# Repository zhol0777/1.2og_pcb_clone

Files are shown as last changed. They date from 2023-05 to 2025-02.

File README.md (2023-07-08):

# 1.2og repro pcb

| front | back | lightbar |
| --- | --- | --- |
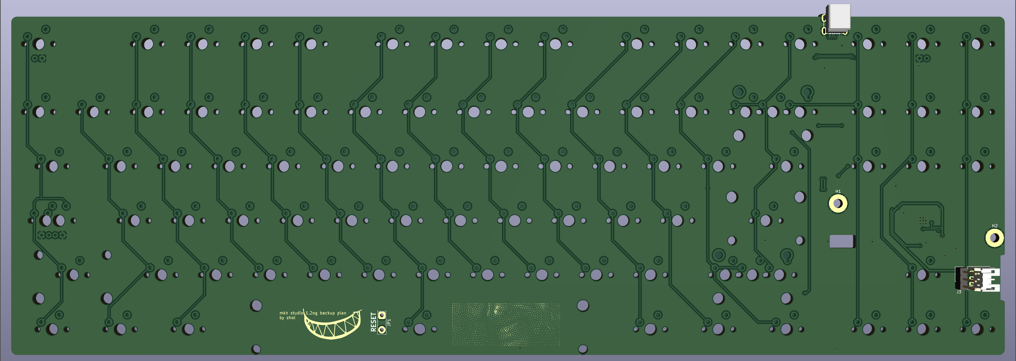
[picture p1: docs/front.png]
front of pcb
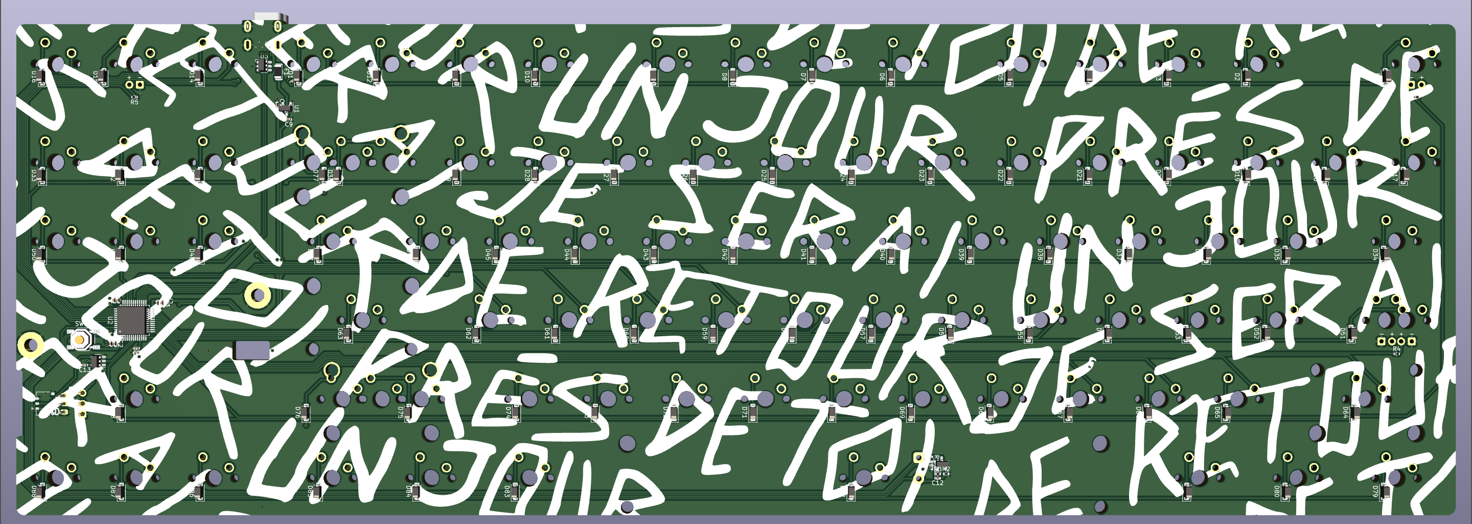
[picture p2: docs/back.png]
back of pcb
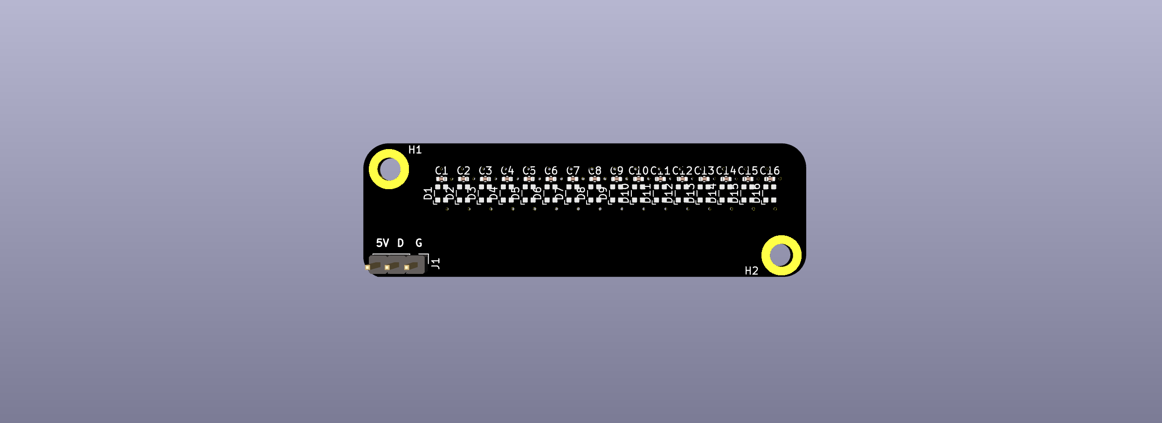
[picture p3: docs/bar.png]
lightbar
|  |  |  |

unfinished attempt to re-create pcb and lightbar for matrix 1.2og.

this has been designed by using pcb edge cuts and plate file that were provided courtesy of astro of matrixlab [here](https://geekhack.org/index.php?topic=106122.msg2901076#msg2901076). without it, re-creating the PCB would be a more maddening and expensive experience. it has 19.02mm x 19.02mm spacing (mostly). 

indicator LEDs on scroll lock and caps lock. JST headers are for s3b ph 3 pin, since that's what it looks like from watching youtube build videos.

## warnings/differences

* The official plate file is treated as the source of truth for where switches should be placed
  * The official 1.2OG PCB edge cuts provided by astro has some arcane spacing rules -
    * 19.02mm on y axis for every row
    * 19.02mm on x axis on first three rows and all arrow keys
    * 19.00mm on row 4 on the main cluster of keys (not arrow keys)
      * The right shift key might still be at where it would be at 19.02mm spacing. The left shift key, i'm not sure, I just placed it where it would have been at 19.02mm spacing.
    * 18.978mmm on modifier keys in the bottom row (not sure if spacebar key is affected)
  * all of this is ignored in favor of sticking with plate dimensions or expected plate dimensions, which are 19.02mm x 19.02mm spacing, EXCEPT
    * 19.024mm y-axis spacing between the function row and regular key cluster
    * the distance between the `M` and `Comma` key is 19.03mm.
* lightbar mounting holes on PCB are slightly off-spec, and in here are plated m3 (edge cuts seem to imply the hole is a bit wider).
* lightbar can now connected to PCB through a molex pico ezmate cable. if you don't like it, you can assemble without it, and solder the s3b connector on yourself.
  * https://www.mouser.com/ProductDetail/Molex/36920-0301 - pick these up, and cut them down the middle to solder wires direct to lightbar
* split backspace and split right shift are included, in case anyone is wants to make a plate that supports those switches. ISO left shift and enter are not included due to laziness.
* usb port placement is mostly guessing.
* 6U spacebar support is added because I miss using my hhkb pro 2.

## misc, thanks

stm32f072 schematic is courtesy of xphoenixd. thanks for teaching me how to design PCB's, man. schematic for ws2812c-2020 rgb chain is inspired by zykrah's [fuyu](https://github.com/zykrah/fuyu). voltage step-up thing for lightbar is inspired by schematic from fuyu and dededecline and olivia's [sst60](https://github.com/dededecline/SST60).

an earlier revision included a basic reset circuit provided by xyz, who also pointed out an issue in the BOM that caused one major issue with the first round of prototypes - were it not for him, I'd probably make two more rounds of protos with the same issue. all love to matthewdias, islandworks, and mel for pointing out a glaring issue with USB, and doubly so for matt for being willing to replace 0402 package resistors pro bono after xyz pointed out how a BOM mistake from me rendered the reset circuit useless. thanks to chippy, phoenix, and chill for misc. advice on how to design this.

i don't know if i'm allowed to license this, given the pcb edge cuts this is based off of were released without a license. nevertheless, they were provided by astro from matrixlab. thank you!

no working prototype has been made for this yet! beware!

## todo
1. ~~fill out BOM real good~~
2. measure and source standoffs that are good enough and ultra low profile screws
3. ~~split main pcb and lightbar pcb separately so jlcpcb production files don't keep bothering each other~~
4. adjust placement of ws2812 based on if it is too far to one side of the lightbar or the other.
5. consider alternative to ws2812 2020 if power consumption/cost reasons.
6. prototype PCB and lightbar
7. ~~firmware (come on, this is basically automated at this point)~~
8. modify lightbar to support both direct soldering and ezmate/jst ach through mouse bite/break off thing or something
  * i think there should be straight ezmate to this, it would make peoples lives so much easier (ignoring how you'd route the extra cable slack)
9. verify this works with original lightbar

## prototyping progress

first revision (in beta branch) failed due to rookie mistake of using USB symbol from one library and footprint from another - the pins between each were in reverse order of each other, which made the prototype useless. whoops! after shipping PCBs to matt for rework, some goons looked over this in kicad pcbeditor and pointed out that the pins over USB were in reverse order.

second prototype arrived 5.31.2023, and exhibited strange behavior - on boot to bootloader mode, dfu-util is able to flash the PCB seemingly fine, and then after reset, the PCB appears recognized by VIAL, at which point **every single device connected over the same USB hub** goes unresponsive. the pcb is also unresponsive. five seconds pass, the PCB dissapears from VIAL, and USB devices begin working again. something deeply bad has happened, so I've tried rearranging all the parts, validating BOM, and praying next revision works.

the latest push to main branch uses molex 0548190519, which I haven't prototyped, but shouldn't be too different otherwise.

i've bought these SMT M2 threaded spacer/standoffs so that lightbar can mount to pcb - https://www.mouser.com/ProductDetail/Wurth-Elektronik/9774015243R - you're probably supposed to use solder paste to assemble these things, but I don't have that, so I don't know, maybe I'll use solder shavings to get these things soldered on. they're slightly smaller than the m3 plated hole on pcb/lightbar, but I don't think it'll matter too much, since they should align one way or another.

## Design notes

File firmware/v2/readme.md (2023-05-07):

# zhol/backup_plan/v1

zhol/backup_plan/v1

A drop-in replacement for the Matrix 1.2OG.

* Keyboard Maintainer: [zhol](https://github.com/zhol0777)
* Hardware Supported: APM32F072
* Hardware Availability: [Github](https://github.com/zhol0777/1.2og_pcb_clone)

Make example for this keyboard (after setting up your build environment):

    make zhol/backup_plan:default

Flashing example for this keyboard:

    make zhol/backup_plan:default:flash

See the [build environment setup](https://docs.qmk.fm/#/getting_started_build_tools) and the [make instructions](https://docs.qmk.fm/#/getting_started_make_guide) for more information. Brand new to QMK? Start with our [Complete Newbs Guide](https://docs.qmk.fm/#/newbs).

## Bootloader

Enter the bootloader in 3 ways:

* **Bootmagic reset**: Hold down the key at (0,0) in the matrix (usually the top left key or Escape) and plug in the keyboard
* **Physical reset button**: Press and hold the reset button on the rear of the pcb (or short the reset jumper beside the spacebar key) for at least 3 seconds.
* **Keycode in layout**: Press the key mapped to `QK_BOOT` if it is available

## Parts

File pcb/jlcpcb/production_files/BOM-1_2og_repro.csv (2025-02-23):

Comment | Designator | Footprint | LCSC | Quantity
10nF | C5 | C_0402_1005Metric | C15195 | 1
100nF | C1,C2,C3,C4 | C_0402_1005Metric | C1525 | 4
S3B | J4 | JST_PH_S3B-PH-K_1x03_P2.00mm_Horizontal | C157929 | 1
4.7uF | C12,C6,C7 | C_0402_1005Metric | C23733 | 3
548190519 | J2 | Molex-0548190519 | C240850 | 1
220 | R2,R3 | R_0402_1005Metric | C25091 | 2
100k | R6 | R_0402_1005Metric | C25741 | 1
10k | R1,R5 | R_0402_1005Metric | C25744 | 2
PRTR5V0U2X | D94 | SOT-143 | C2827688 | 1
Pico EzMate | J1 | Molex_Pico-EZmate_78171-0003_1x03-1MP_P1.20mm_Vertical | C2997426 | 1
SW_Push | SW95 | SW_SPST_TL3342 | C318884 | 1
1uF | C10,C11,C8,C9 | C_0402_1005Metric | C52923 | 4
XC6206PxxxMR | U1 | SOT-23 | C5446 | 1
SN74LVC1T45DBV | U3 | SOT-23-6-routable | C7843 | 1
D_Small | D1,D10,D11,D12,D13,D14,D15,D16,D17,D18,D19,D2,D20,D21,D22,D23,D24,D25,D26,D27,D28,D29,D3,D30,D31,D32,D33,D34,D35,D36,D37,D38,D39,D4,D40,D41,D42,D43,D44,D45,D46,D47,D48,D49,D5,D50,D51,D52,D53,D54,D55,D56,D57,D58,D59,D6,D60,D61,D62,D63,D64,D65,D66,D67,D68,D69,D7,D70,D71,D72,D73,D74,D75,D76,D77,D78,D79,D8,D80,D81,D82,D83,D84,D85,D86,D87,D88,D9,D93 | D_SOD-123 | C81598 | 89
STM32F072C8Tx | U2 | LQFP-48_7x7mm_P0.5mm | C81720 | 1
2N7002 | Q1 | SOT-23 | C8545 | 1
500mA | F1 | Fuse_1206_3216Metric | C883122 | 1

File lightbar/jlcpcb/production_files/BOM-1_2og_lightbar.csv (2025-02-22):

Comment | Designator | Footprint | LCSC | Quantity
100nF | C1,C10,C11,C12,C13,C14,C15,C16,C2,C3,C4,C5,C6,C7,C8,C9 | C_0402_1005Metric | C1525 | 16
500 | R1,R2 | R_0805_2012Metric | C2828711 | 2
SK6812_EC15 | D1,D10,D11,D12,D13,D14,D15,D16,D2,D3,D4,D5,D6,D7,D8,D9 | LED_SK6812_EC15_1.5x1.5mm | C2890035 | 16
Conn_01x03_Shielded | J2 | Molex_Pico-EZmate_78171-0003_1x03-1MP_P1.20mm_Vertical | C2997426 | 1

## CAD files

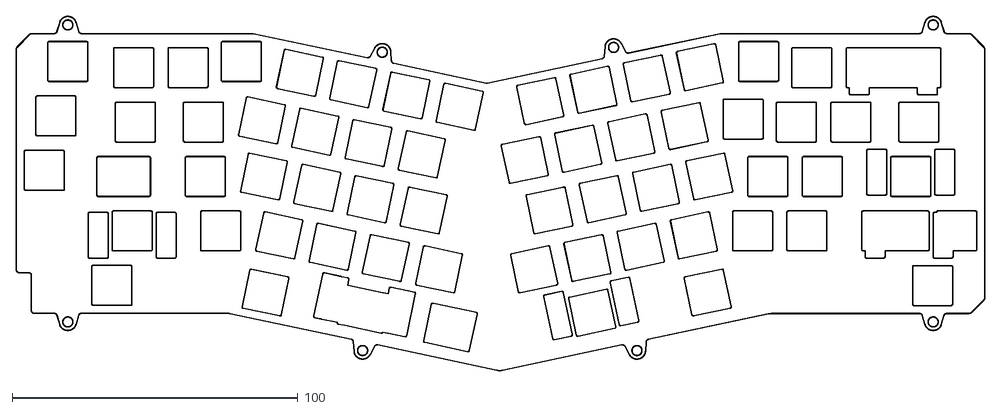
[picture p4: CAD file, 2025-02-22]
pcb/1_2og_repro-Edge_Cuts.dxf
338.8 x 123.9

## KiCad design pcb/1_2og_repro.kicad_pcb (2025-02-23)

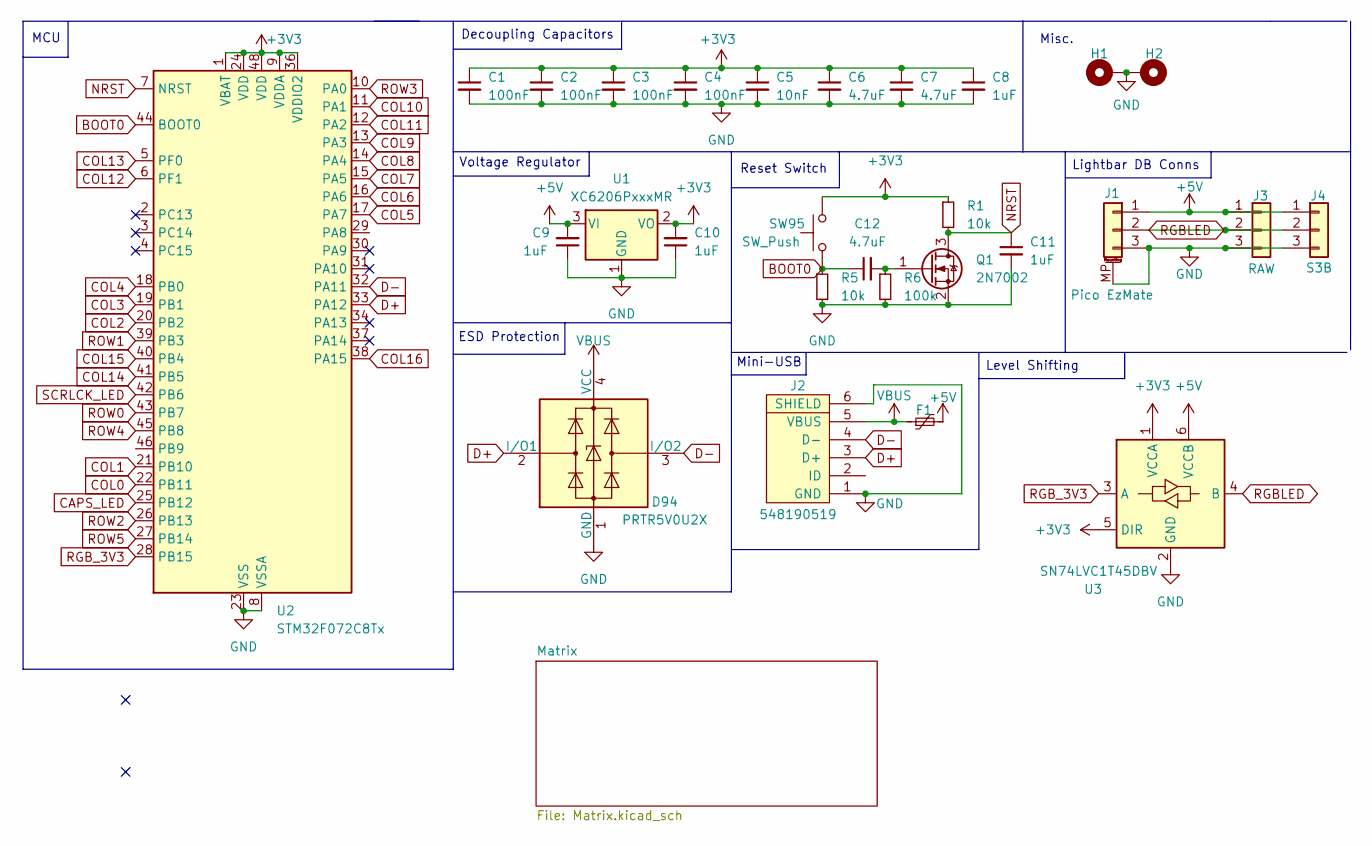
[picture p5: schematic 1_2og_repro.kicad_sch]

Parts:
C1, C2, C3, C4: 100nF; C_0402_1005Metric
C5: 10nF; C_0402_1005Metric
C6, C7, C12: 4.7uF; C_0402_1005Metric
C8, C9, C10, C11: 1uF; C_0402_1005Metric
D94: PRTR5V0U2X; SOT-143
F1: 500mA; Fuse_1206_3216Metric
H1, H2: MountingHole_Pad; MountingHole_3mm_Pad
J1: Pico EzMate; Molex_Pico-EZmate_78171-0003_1x03-1MP_P1.20mm_Vertical
J2: 548190519; Molex-0548190519
J3: RAW; PinHeader_1x03_P2.54mm_Vertical
J4: S3B; JST_PH_S3B-PH-K_1x03_P2.00mm_Horizontal
Q1: 2N7002; SOT-23
R1, R5: 10k; R_0402_1005Metric
R6: 100k; R_0402_1005Metric
SW95: SW_Push; SW_SPST_TL3342
U1: XC6206PxxxMR; SOT-23
U2: STM32F072C8Tx; LQFP-48_7x7mm_P0.5mm
U3: SN74LVC1T45DBV; SOT-23-6

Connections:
+3V3: C1.1, C2.1, C3.1, C4.1, C5.1, C6.1, C7.1, C8.1, C10.2, R1.1, SW95.2, U1.2 (VO), U2.1 (VBAT), U2.9 (VDDA), U2.24 (VDD), U2.36 (VDDIO2), U2.48 (VDD), U3.1 (VCCA), U3.5 (DIR)
+5V: C9.2, F1.2, J1.1, J3.1, J4.1, U1.3 (VI), U3.6 (VCCB)
BOOT0: C12.1, R5.1, SW95.1, U2.44 (BOOT0)
CAPS_LED: U2.25 (PB12); also elsewhere on the board
COL0: U2.22 (PB11); also elsewhere on the board
COL1: U2.21 (PB10); also elsewhere on the board
COL2: U2.20 (PB2); also elsewhere on the board
COL3: U2.19 (PB1); also elsewhere on the board
COL4: U2.18 (PB0); also elsewhere on the board
COL5: U2.17 (PA7); also elsewhere on the board
COL6: U2.16 (PA6); also elsewhere on the board
COL7: U2.15 (PA5); also elsewhere on the board
COL8: U2.14 (PA4); also elsewhere on the board
COL9: U2.13 (PA3); also elsewhere on the board
COL10: U2.11 (PA1); also elsewhere on the board
COL11: U2.12 (PA2); also elsewhere on the board
COL12: U2.6 (PF1); also elsewhere on the board
COL13: U2.5 (PF0); also elsewhere on the board
COL14: U2.41 (PB5); also elsewhere on the board
COL15: U2.40 (PB4); also elsewhere on the board
COL16: U2.38 (PA15); also elsewhere on the board
D+: D94.2 (I/O1), J2.3 (D+), U2.33 (PA12)
D-: D94.3 (I/O2), J2.4 (D-), U2.32 (PA11)
GND: C1.2, C2.2, C3.2, C4.2, C5.2, C6.2, C7.2, C8.2, C9.1, C10.1, C11.2, D94.1 (GND), H1.1, H2.1, J1.3, J1.MP (MountPin), J2.1 (GND), J2.6 (SHIELD), J3.3, J4.3, Q1.2 (S), R5.2, R6.2, U1.1 (GND), U2.8 (VSSA), U2.23 (VSS), U2.35 (VSS), U2.47 (VSS), U3.2 (GND); also elsewhere on the board
NRST: C11.1, Q1.3 (D), R1.2, U2.7 (NRST)
unnamed: C12.2, Q1.1 (G), R6.1
RGBLED: J1.2, J3.2, J4.2, U3.4 (B)
RGB_3V3: U2.28 (PB15), U3.3 (A)
ROW0: U2.43 (PB7); also elsewhere on the board
ROW1: U2.39 (PB3); also elsewhere on the board
ROW2: U2.26 (PB13); also elsewhere on the board
ROW3: U2.10 (PA0); also elsewhere on the board
ROW4: U2.45 (PB8); also elsewhere on the board
ROW5: U2.27 (PB14); also elsewhere on the board
SCRLCK_LED: U2.42 (PB6); also elsewhere on the board
VBUS: D94.4 (VCC), F1.1, J2.5 (VBUS)

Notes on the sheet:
Level Shifting
Mini-USB
Reset Switch
MCU
ESD Protection
Voltage Regulator
Misc.
Lightbar DB Conns
Decoupling Capacitors

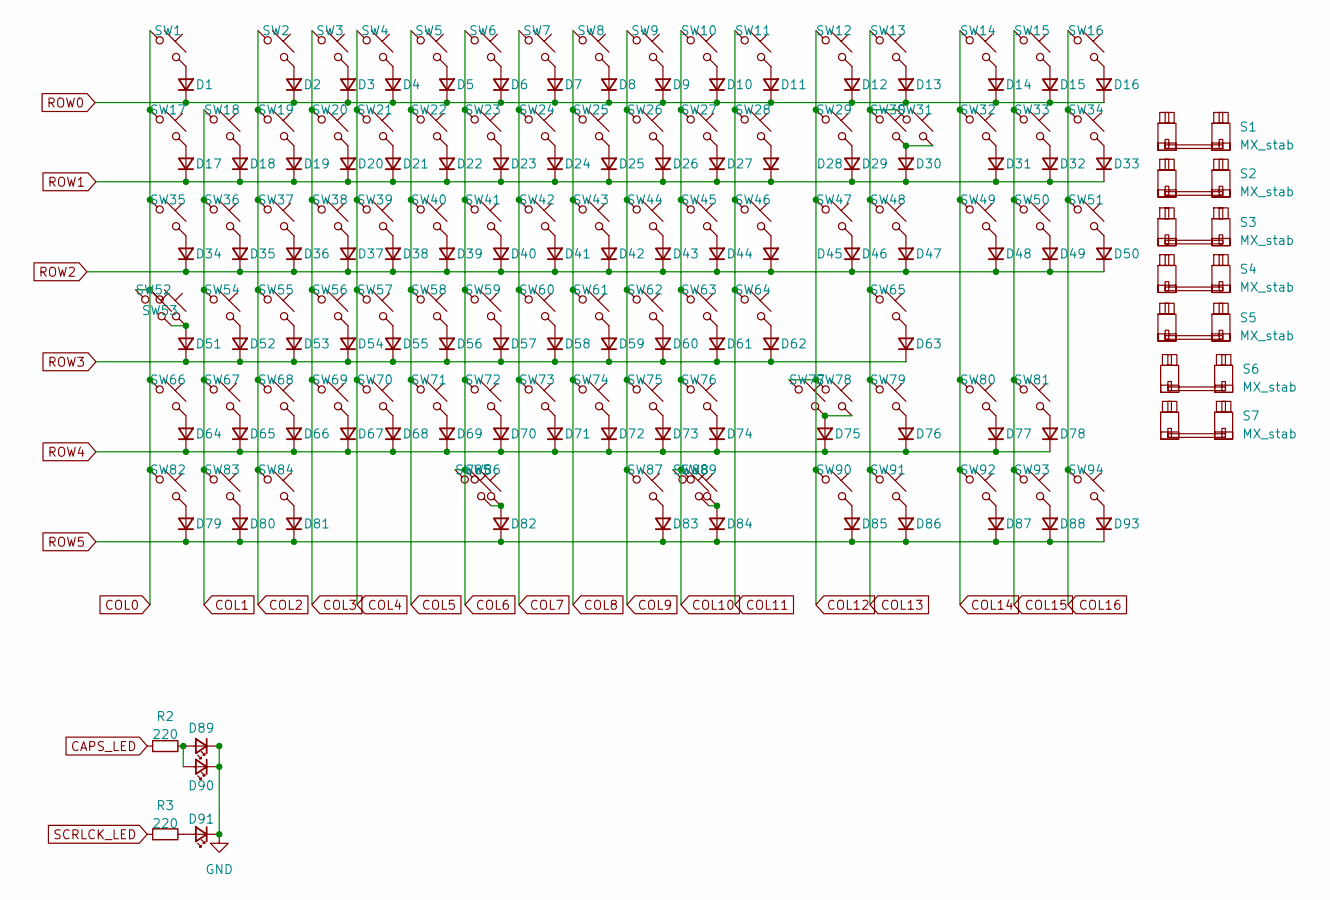
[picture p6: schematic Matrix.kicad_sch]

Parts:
D1, D2, D3, D4, D5, D6, D7, D8, D9, D10, D11, D12, D13, D14, D15, D16, D17, D18, D19, D20, D21, D22, D23, D24, D25, D26, D27, D28, D29, D30, D31, D32, D33, D34, D35, D36, D37, D38, D39, D40, D41, D42, D43, D44, D45, D46, D47, D48, D49, D50, D51, D52, D53, D54, D55, D56, D57, D58, D59, D60, D61, D62, D63, D64, D65, D66, D67, D68, D69, D70, D71, D72, D73, D74, D75, D76, D77, D78, D79, D80, D81, D82, D83, D84, D85, D86, D87, D88, D93: D_Small; D_SOD-123
D89, D91: LED_Small; LED_MX_3mm
D90: LED_Small; LED_MX_3mm-ROT
R2, R3: 220; R_0402_1005Metric
S1: MX_stab; STAB_MX_P_2u
S2, S3: MX_stab; STAB_MX_2.25u
S4: MX_stab; STAB_MX_P_2.75u
S5: MX_stab; STAB_MX_7u
S6: MX_stab; STAB_MX_6u
S7: MX_stab; STAB_MX_10u
SW1, SW2, SW3, SW4, SW5, SW6, SW7, SW8, SW9, SW10, SW11, SW12, SW13, SW14, SW15, SW16, SW17, SW18, SW19, SW20, SW21, SW22, SW23, SW24, SW25, SW26, SW27, SW28, SW29, SW30, SW31, SW32, SW33, SW34, SW36, SW37, SW38, SW39, SW40, SW41, SW42, SW43, SW44, SW45, SW46, SW47, SW49, SW50, SW51, SW54, SW55, SW56, SW57, SW58, SW59, SW60, SW61, SW62, SW63, SW64, SW65, SW66, SW67, SW68, SW69, SW70, SW71, SW72, SW73, SW74, SW75, SW76, SW78, SW79, SW80, SW81, SW83, SW85, SW86, SW88, SW90, SW92, SW93, SW94: MX_SW_solder; SW_MX_1u
SW35, SW48, SW82, SW84, SW87, SW89, SW91: MX_SW_solder; SW_MX_1.5u
SW52: MX_SW_solder; SW_MX_1.75u_STP_1.25
SW53, SW77: MX_SW_solder; SW_MX_1.75u

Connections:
CAPS_LED: R2.1; also elsewhere on the board
COL0: SW1.1, SW17.1, SW35.1, SW52.1, SW53.1, SW66.1, SW82.1; also elsewhere on the board
COL1: SW18.1, SW36.1, SW54.1, SW67.1, SW83.1; also elsewhere on the board
COL2: SW2.1, SW19.1, SW37.1, SW55.1, SW68.1, SW84.1; also elsewhere on the board
COL3: SW3.1, SW20.1, SW38.1, SW56.1, SW69.1; also elsewhere on the board
COL4: SW4.1, SW21.1, SW39.1, SW57.1, SW70.1; also elsewhere on the board
COL5: SW5.1, SW22.1, SW40.1, SW58.1, SW71.1; also elsewhere on the board
COL6: SW6.1, SW23.1, SW41.1, SW59.1, SW72.1, SW85.1, SW86.1; also elsewhere on the board
COL7: SW7.1, SW24.1, SW42.1, SW60.1, SW73.1; also elsewhere on the board
COL8: SW8.1, SW25.1, SW43.1, SW61.1, SW74.1; also elsewhere on the board
COL9: SW9.1, SW26.1, SW44.1, SW62.1, SW75.1, SW87.1; also elsewhere on the board
COL10: SW10.1, SW27.1, SW45.1, SW63.1, SW76.1, SW88.1, SW89.1; also elsewhere on the board
COL11: SW11.1, SW28.1, SW46.1, SW64.1; also elsewhere on the board
COL12: SW12.1, SW29.1, SW47.1, SW77.1, SW78.1, SW90.1; also elsewhere on the board
COL13: SW13.1, SW30.1, SW31.1, SW48.1, SW65.1, SW79.1, SW91.1; also elsewhere on the board
COL14: SW14.1, SW32.1, SW49.1, SW80.1, SW92.1; also elsewhere on the board
COL15: SW15.1, SW33.1, SW50.1, SW81.1, SW93.1; also elsewhere on the board
COL16: SW16.1, SW34.1, SW51.1, SW94.1; also elsewhere on the board
GND: D89.1 (K), D90.1 (K), D91.1 (K); also elsewhere on the board
unnamed: D1.2 (A), SW1.2
unnamed: D2.2 (A), SW2.2
unnamed: D3.2 (A), SW3.2
unnamed: D4.2 (A), SW4.2
unnamed: D5.2 (A), SW5.2
unnamed: D6.2 (A), SW6.2
unnamed: D7.2 (A), SW7.2
unnamed: D8.2 (A), SW8.2
unnamed: D9.2 (A), SW9.2
unnamed: D10.2 (A), SW10.2
unnamed: D11.2 (A), SW11.2
unnamed: D12.2 (A), SW12.2
unnamed: D13.2 (A), SW13.2
unnamed: D14.2 (A), SW14.2
unnamed: D15.2 (A), SW15.2
unnamed: D16.2 (A), SW16.2
unnamed: D17.2 (A), SW17.2
unnamed: D18.2 (A), SW18.2
unnamed: D19.2 (A), SW19.2
unnamed: D20.2 (A), SW20.2
unnamed: D21.2 (A), SW21.2
unnamed: D22.2 (A), SW22.2
unnamed: D23.2 (A), SW23.2
unnamed: D24.2 (A), SW24.2
unnamed: D25.2 (A), SW25.2
unnamed: D26.2 (A), SW26.2
unnamed: D27.2 (A), SW27.2
unnamed: D28.2 (A), SW28.2
unnamed: D29.2 (A), SW29.2
unnamed: D30.2 (A), SW30.2, SW31.2
unnamed: D31.2 (A), SW32.2
unnamed: D32.2 (A), SW33.2
unnamed: D33.2 (A), SW34.2
unnamed: D34.2 (A), SW35.2
unnamed: D35.2 (A), SW36.2
unnamed: D36.2 (A), SW37.2
unnamed: D37.2 (A), SW38.2
unnamed: D38.2 (A), SW39.2
unnamed: D39.2 (A), SW40.2
unnamed: D40.2 (A), SW41.2
unnamed: D41.2 (A), SW42.2
unnamed: D42.2 (A), SW43.2
unnamed: D43.2 (A), SW44.2
unnamed: D44.2 (A), SW45.2
unnamed: D45.2 (A), SW46.2
unnamed: D46.2 (A), SW47.2
unnamed: D47.2 (A), SW48.2
unnamed: D48.2 (A), SW49.2
unnamed: D49.2 (A), SW50.2
unnamed: D50.2 (A), SW51.2
unnamed: D51.2 (A), SW52.2, SW53.2
unnamed: D52.2 (A), SW54.2
unnamed: D53.2 (A), SW55.2
unnamed: D54.2 (A), SW56.2
unnamed: D55.2 (A), SW57.2
unnamed: D56.2 (A), SW58.2
unnamed: D57.2 (A), SW59.2
unnamed: D58.2 (A), SW60.2
unnamed: D59.2 (A), SW61.2
unnamed: D60.2 (A), SW62.2
unnamed: D61.2 (A), SW63.2
unnamed: D62.2 (A), SW64.2
unnamed: D63.2 (A), SW65.2
unnamed: D64.2 (A), SW66.2
unnamed: D65.2 (A), SW67.2
unnamed: D66.2 (A), SW68.2
unnamed: D67.2 (A), SW69.2
unnamed: D68.2 (A), SW70.2
unnamed: D69.2 (A), SW71.2
unnamed: D70.2 (A), SW72.2
unnamed: D71.2 (A), SW73.2
unnamed: D72.2 (A), SW74.2
unnamed: D73.2 (A), SW75.2
unnamed: D74.2 (A), SW76.2
unnamed: D75.2 (A), SW77.2, SW78.2
unnamed: D76.2 (A), SW79.2
unnamed: D77.2 (A), SW80.2
unnamed: D78.2 (A), SW81.2
unnamed: D79.2 (A), SW82.2
unnamed: D80.2 (A), SW83.2
unnamed: D81.2 (A), SW84.2
unnamed: D82.2 (A), SW85.2, SW86.2
unnamed: D83.2 (A), SW87.2
unnamed: D84.2 (A), SW88.2, SW89.2
unnamed: D85.2 (A), SW90.2
unnamed: D86.2 (A), SW91.2
unnamed: D87.2 (A), SW92.2
unnamed: D88.2 (A), SW93.2
unnamed: D89.2 (A), D90.2 (A), R2.2
unnamed: D91.2 (A), R3.2
unnamed: D93.2 (A), SW94.2
ROW0: D1.1 (K), D2.1 (K), D3.1 (K), D4.1 (K), D5.1 (K), D6.1 (K), D7.1 (K), D8.1 (K), D9.1 (K), D10.1 (K), D11.1 (K), D12.1 (K), D13.1 (K), D14.1 (K), D15.1 (K), D16.1 (K); also elsewhere on the board
ROW1: D17.1 (K), D18.1 (K), D19.1 (K), D20.1 (K), D21.1 (K), D22.1 (K), D23.1 (K), D24.1 (K), D25.1 (K), D26.1 (K), D27.1 (K), D28.1 (K), D29.1 (K), D30.1 (K), D31.1 (K), D32.1 (K), D33.1 (K); also elsewhere on the board
ROW2: D34.1 (K), D35.1 (K), D36.1 (K), D37.1 (K), D38.1 (K), D39.1 (K), D40.1 (K), D41.1 (K), D42.1 (K), D43.1 (K), D44.1 (K), D45.1 (K), D46.1 (K), D47.1 (K), D48.1 (K), D49.1 (K), D50.1 (K); also elsewhere on the board
ROW3: D51.1 (K), D52.1 (K), D53.1 (K), D54.1 (K), D55.1 (K), D56.1 (K), D57.1 (K), D58.1 (K), D59.1 (K), D60.1 (K), D61.1 (K), D62.1 (K), D63.1 (K); also elsewhere on the board
ROW4: D64.1 (K), D65.1 (K), D66.1 (K), D67.1 (K), D68.1 (K), D69.1 (K), D70.1 (K), D71.1 (K), D72.1 (K), D73.1 (K), D74.1 (K), D75.1 (K), D76.1 (K), D77.1 (K), D78.1 (K); also elsewhere on the board
ROW5: D79.1 (K), D80.1 (K), D81.1 (K), D82.1 (K), D83.1 (K), D84.1 (K), D85.1 (K), D86.1 (K), D87.1 (K), D88.1 (K), D93.1 (K); also elsewhere on the board
SCRLCK_LED: R3.1; also elsewhere on the board

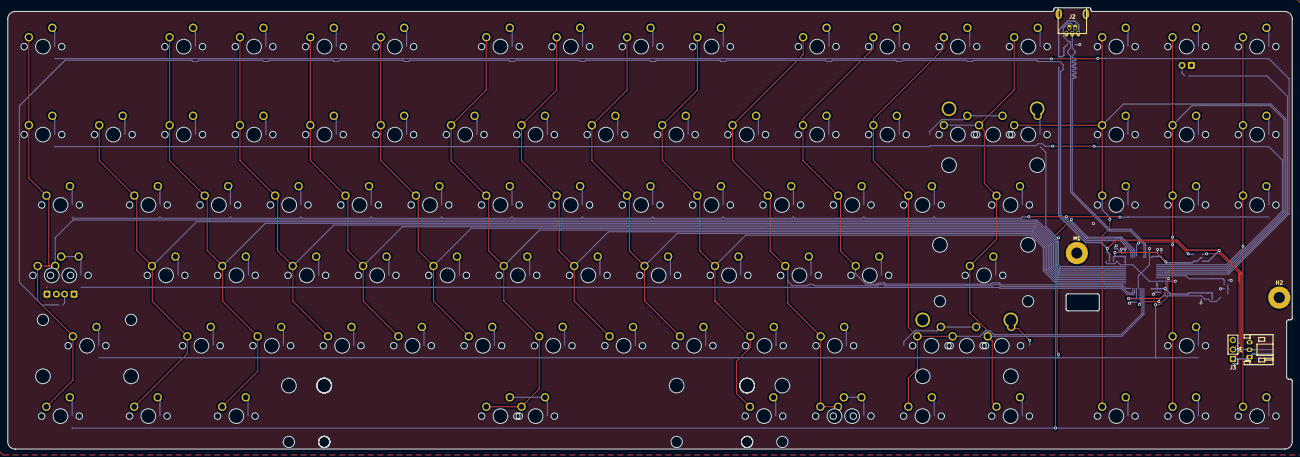
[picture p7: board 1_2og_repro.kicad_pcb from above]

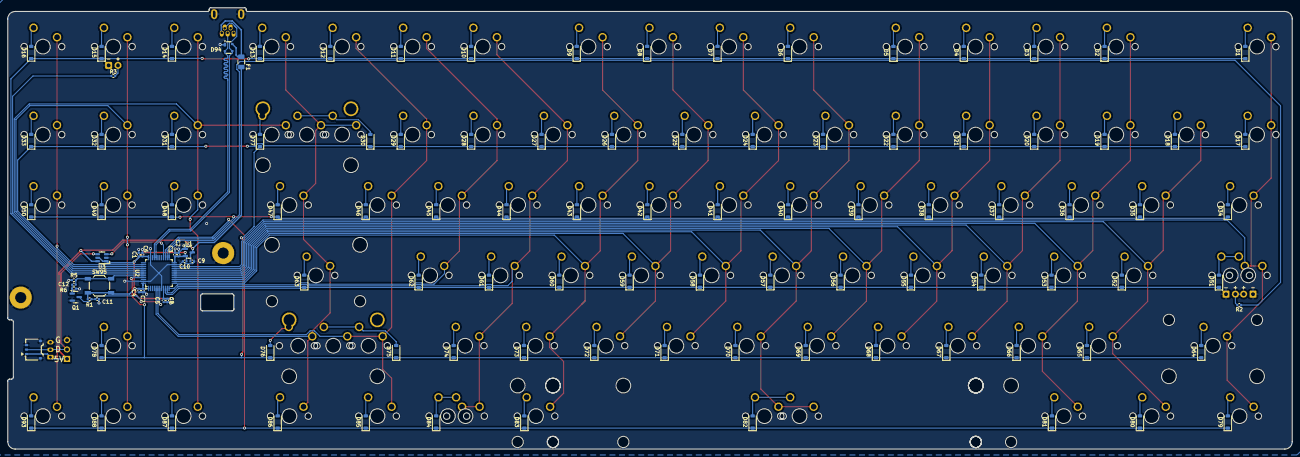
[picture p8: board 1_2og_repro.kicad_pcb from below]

Board: 2 copper layers, 347.1 x 119.3 mm, 223 parts (115 on the bottom side), 127 nets.

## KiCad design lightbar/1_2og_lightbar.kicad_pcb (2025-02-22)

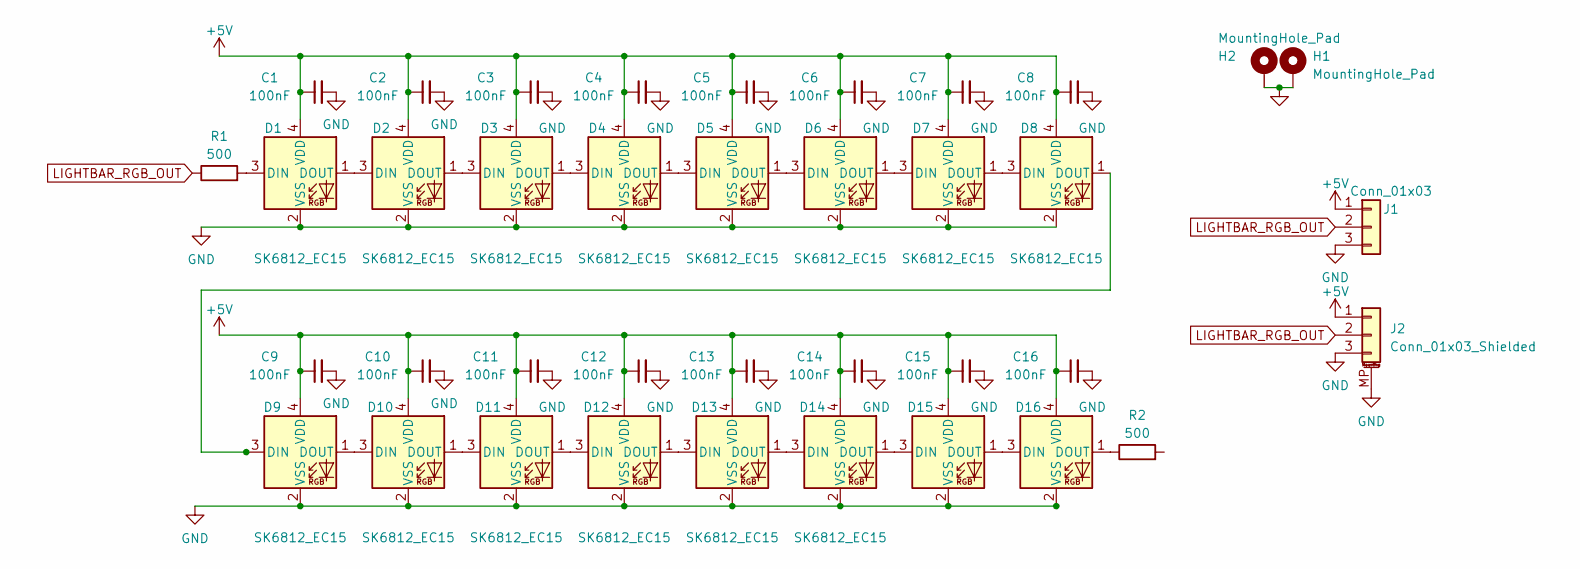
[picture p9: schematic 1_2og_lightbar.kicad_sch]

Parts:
C1, C2, C3, C4, C5, C6, C7, C8, C9, C10, C11, C12, C13, C14, C15, C16: 100nF; C_0402_1005Metric
D1, D2, D3, D4, D5, D6, D7, D8, D9, D10, D11, D12, D13, D14, D15, D16: SK6812_EC15; LED_SK6812_EC15_1.5x1.5mm
H1, H2: MountingHole_Pad; MountingHole_3mm_Pad
J1: Conn_01x03; PinHeader_1x03_P2.54mm_Vertical
J2: Conn_01x03_Shielded; Molex_Pico-EZmate_78171-0003_1x03-1MP_P1.20mm_Vertical
R1, R2: 500; R_0805_2012Metric

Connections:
+5V: C1.1, C2.1, C3.1, C4.1, C5.1, C6.1, C7.1, C8.1, C9.1, C10.1, C11.1, C12.1, C13.1, C14.1, C15.1, C16.1, D1.4 (VDD), D2.4 (VDD), D3.4 (VDD), D4.4 (VDD), D5.4 (VDD), D6.4 (VDD), D7.4 (VDD), D8.4 (VDD), D9.4 (VDD), D10.4 (VDD), D11.4 (VDD), D12.4 (VDD), D13.4 (VDD), D14.4 (VDD), D15.4 (VDD), D16.4 (VDD), J1.1, J2.1
GND: C1.2, C2.2, C3.2, C4.2, C5.2, C6.2, C7.2, C8.2, C9.2, C10.2, C11.2, C12.2, C13.2, C14.2, C15.2, C16.2, D1.2 (VSS), D2.2 (VSS), D3.2 (VSS), D4.2 (VSS), D5.2 (VSS), D6.2 (VSS), D7.2 (VSS), D8.2 (VSS), D9.2 (VSS), D10.2 (VSS), D11.2 (VSS), D12.2 (VSS), D13.2 (VSS), D14.2 (VSS), D15.2 (VSS), D16.2 (VSS), H1.1, H2.1, J1.3, J2.3, J2.MP (MountPin)
LIGHTBAR_RGB_OUT: J1.2, J2.2, R1.1
unnamed: D1.3 (DIN), R1.2
unnamed: D1.1 (DOUT), D2.3 (DIN)
unnamed: D2.1 (DOUT), D3.3 (DIN)
unnamed: D3.1 (DOUT), D4.3 (DIN)
unnamed: D4.1 (DOUT), D5.3 (DIN)
unnamed: D5.1 (DOUT), D6.3 (DIN)
unnamed: D6.1 (DOUT), D7.3 (DIN)
unnamed: D7.1 (DOUT), D8.3 (DIN)
unnamed: D8.1 (DOUT), D9.3 (DIN)
unnamed: D9.1 (DOUT), D10.3 (DIN)
unnamed: D10.1 (DOUT), D11.3 (DIN)
unnamed: D11.1 (DOUT), D12.3 (DIN)
unnamed: D12.1 (DOUT), D13.3 (DIN)
unnamed: D13.1 (DOUT), D14.3 (DIN)
unnamed: D14.1 (DOUT), D15.3 (DIN)
unnamed: D15.1 (DOUT), D16.3 (DIN)
unnamed: D16.1 (DOUT), R2.1

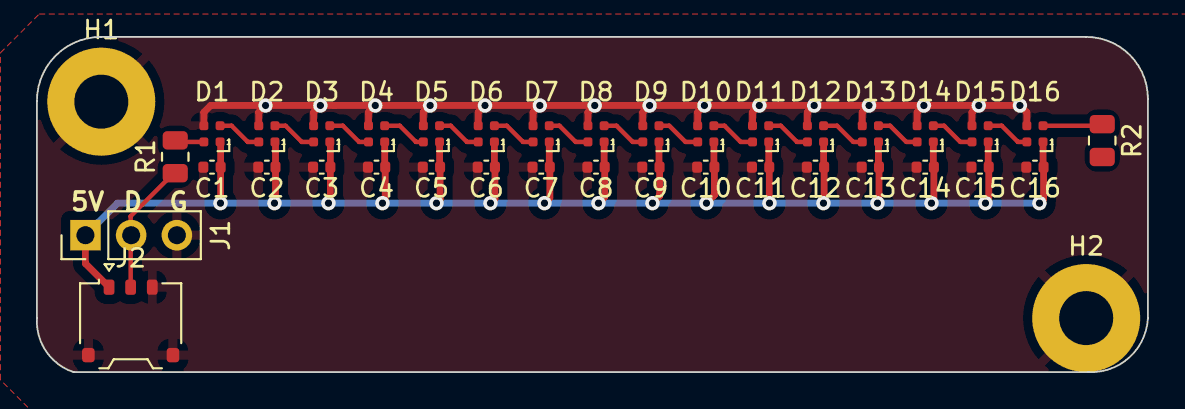
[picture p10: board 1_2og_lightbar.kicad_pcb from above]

Board: 2 copper layers, 61.7 x 18.6 mm, 38 parts (0 on the bottom side), 20 nets.

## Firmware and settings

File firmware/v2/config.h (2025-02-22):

// Copyright 2023 @zhol0777
// SPDX-License-Identifier: GPL-2.0-or-later

#pragma once

/*
 * Feature disable options
 *  These options are also useful to firmware size reduction.
 */

/* disable debug print */
//#define NO_DEBUG

/* disable print */
//#define NO_PRINT

/* disable action features */
//#define NO_ACTION_LAYER
//#define NO_ACTION_TAPPING
//#define NO_ACTION_ONESHOT

#define WS2812_PWM_DRIVER PWMD1
#define WS2812_PWM_CHANNEL 3
#define WS2812_PWM_PAL_MODE 2
#define WS2812_PWM_COMPLEMENTARY_OUTPUT
#define WS2812_PWM_DMA_STREAM STM32_DMA1_STREAM5
#define WS2812_PWM_DMA_CHANNEL 5
#define WS2812_BYTE_ORDER WS2812_BYTE_ORDER_RGB

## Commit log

2023-05-05 add lightbar kinda (gerbers have not been fully updated yet, bom is broken)
    [1_2og_lightbar-CuBottom.gbr, 1_2og_lightbar-CuTop.gbr, 1_2og_lightbar-EdgeCuts.gbr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]
2023-05-05 dual jst-ph and ezmate support on pcb
    [1_2og_repro-CuBottom.gbr, 1_2og_repro-CuTop.gbr, 1_2og_repro-EdgeCuts.gbr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]
2023-05-05 reorganizing, re-do BOM
    [1_2og_lightbar-CuBottom.gbr, 1_2og_lightbar-CuTop.gbr, 1_2og_lightbar-EdgeCuts.gbr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]
2023-05-05 routing improvements
    [1_2og_repro-CuBottom.gbr, 1_2og_repro-CuTop.gbr, 1_2og_repro-EdgeCuts.gbr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]
2023-05-06 spacing updates, silkscreens and etc
    [1_2og_lightbar-CuBottom.gbr, 1_2og_lightbar-CuTop.gbr, 1_2og_lightbar-EdgeCuts.gbr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]
2023-05-06 fix 3v3 connections to mcu
    [1_2og_repro-CuBottom.gbr, 1_2og_repro-CuTop.gbr, 1_2og_repro-EdgeCuts.gbr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]
2023-05-07 re-route pcb
    [1_2og_lightbar-CuBottom.gbr, 1_2og_lightbar-CuTop.gbr, 1_2og_lightbar-EdgeCuts.gbr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]
2023-05-07 do not use PB2 as column pin
    [1_2og_repro-CuBottom.gbr, 1_2og_repro-CuTop.gbr, 1_2og_repro-EdgeCuts.gbr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]
2023-05-08 redo reset circuit component placement, fix bottom row spacing with 19.03mm weird thing
    [1_2og_repro-CuBottom.gbr, 1_2og_repro-CuTop.gbr, 1_2og_repro-EdgeCuts.gbr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]
2023-05-19 fix BOM
    [BOM-1_2og_repro.csv]
2023-05-22 fix usb pin symbol footpring mixup
    [1_2og_repro-CuBottom.gbr, 1_2og_repro-CuTop.gbr, 1_2og_repro-EdgeCuts.gbr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]
2023-05-31 add 6u support (firmware does not reflect this yet), usb 0548190519
    previous USB is annoying to hand-solder without wick, using through-hole
    pins may be less of a pain. 6u support is added because I miss my HHKB.
    [1_2og_repro-CuBottom.gbr, 1_2og_repro-CuTop.gbr, 1_2og_repro-EdgeCuts.gbr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]
2023-07-03 REMAKE - FIRMWARE NEEDS UPDATES
    [1_2og_repro-CuBottom.gbr, 1_2og_repro-CuTop.gbr, 1_2og_repro-EdgeCuts.gbr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]
2023-07-07 update gerbers, change mounting hole dimensions
    [1_2og_lightbar-CuBottom.gbr, 1_2og_lightbar-CuTop.gbr, 1_2og_lightbar-EdgeCuts.gbr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]
2023-07-07 ok juggle a few pins around
    [1_2og_repro-CuBottom.gbr, 1_2og_repro-CuTop.gbr, 1_2og_repro-EdgeCuts.gbr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]
2023-07-08 tune differential pair, reroute to remove redundant vias
    [1_2og_repro-CuBottom.gbr, 1_2og_repro-CuTop.gbr, 1_2og_repro-EdgeCuts.gbr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]
2025-02-23 sunday at the waterpark
    [1_2og_repro-CuBottom.gbr, 1_2og_repro-CuTop.gbr, 1_2og_repro-EdgeCuts.gbr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]
